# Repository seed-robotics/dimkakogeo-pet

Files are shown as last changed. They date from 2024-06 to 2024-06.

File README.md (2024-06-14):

# PetFeeder Project
## Περιγραφή 
Θέλοντας να βοηθήσουμε στο πρόβλημα ταΐσματος των κατοικίδιων ζώων η ομάδα μας κατασέυσασε μια αυτόματη ταΐστρα. Ψάχνοντας στο διαδίκτυο είδαμε ότι αν και υπάρχουν αρκετές αυτόματες ταΐστρες, οι περισσότερες δεν αφορούν παραπάνω από ένα ζώο ή δεν έχουν δυνατότητα να βγάζουν διαφορετικές τροφές. Επειδή οι σκύλοι έχουν διαφορετικές διατροφικές ανάγκες σε σχέση με τις γάτες σκεφτήκαμε να φτιάξουμε μια ταΐστρα η οποία μέσω Τεχνητής Νοημοσύνης να μπορεί να ξεχωρίσει τι είδους ζωάκι υπάρχει εκείνη τη στιγμή στο προσκήνιο και να προσφέρει το κατάλληλο είδος τροφής. 

Aποτελείται από δύο δοχεία αποθήκευσης της ξηράς τροφής, ένα το οποίο περιέχει κατάλληλη τροφή για γάτες και ένα για σκύλους. Ανάλογα με το είδος του ζώου που έχει πλησιάσει, ενεργοποιείται και διαφορετικός κινητήρας και ελευθερώνεται τροφή από διαφορετικό δοχείο ώστε να καταλήγει στο μπολ. Η ανίχνευση της κίνησης γίνεται μέσω της κάμερας και όταν περάσει κάτι μπροστά από την ταΐστρα και γίνει ανίχνευση κίνησης, η εικόνα αυτή τροφοδοτείται σε μοντέλο μηχανικής μάθησης αναγνώρισης εικόνας. Ανάλογα με το αποτέλεσμα (γάτα/σκύλος/υπόβαθρο) ενεργοποιείται και ο αντίστοιχος κινητήρας. 

<div style="display: flex; justify-content: center;">
  dimkakogeopet
</div>

Εκτός από αναγνώριση γάτας/σκύλου/υποβάθρου θα μπορεί με μικρές αλλαγές να χρησιμοποιηθεί και μόνο για ένα είδος ζώου(πχ δύο σκύλοι με διαφορετικό μέγεθος ή ένα δοχείο με τροφή ένα με λιχουδιές, αλλεργίες κλπ.) ή σε εξωτερικό χώρο προσφέροντας τροφή σε αδέσποτα ζώα. Επίσης μελλοντικά μπορούν να προστεθούν και άλλες λειτουργίες όπως λειτουργία παρακολούθησης μέσω βίντεο, εισαγωγή αισθητήρων πίεσης με σκοπό την εκπαίδευση του κατοικίδιου, απομακρυσμένη λειτουργία μέσω Wifi κ.α.

## Λίστα Υλικών
- Raspberry Pi Zero 2 W
- microSD card
- Raspberry Pi Camera Module
- Raspberry Pi Zero Camera Adapter
- 2*Servo mg996r
- mini HDMI to HDMI cable
- microUSB power Supply

## Οδηγίες κατασκευής 
Για την εκτύπωση μπορείτε να βρείτε τα αρχεία στον φάκελο STLs. 
Επιπλέον για την κατασκευή θα χρειαστείτε:
- 8x M2.5 mm x 12mm βίδες για την στήριξη της κάμερας και του Raspberry Pi
- 2x M3mm x 10-30mm βιδες για την στήριξη του κοχλία
- 4x Μ3 x 10mm βίδες βίδες

## Οδηγίες για το πρόγραμμα
Σε καινούργια εγκατάσταση του Raspberry Pi OS: 
```
sudo apt update
sudo apt upgrade
sudo apt install python3-pip
cd dimkakogeo-pet/code
pip3 install -r requirements.txt
```
Στη συνέχεια μπορείτε να τρέξετε το πρόγραμμα main.py 
```
./main.py
```

## About Us
- **Όνομα Ομάδας:** DimKakoGeo-Pet
- **Μέλη Ομάδας:**
  - Δημητρης Ματσούκας
  - Γιάννης Κακογιαννάκης
  - Δημήτρης Γεωργιάδης
  - Πέτρος Κρητικός
- **Υπέυθυνος:** Λάμπρος Νέστωρας
- **Εκπαιδευτικό Κέντρο:** Seed Robotics

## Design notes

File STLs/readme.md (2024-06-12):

## Οδηγίες 

Για τη συναρμολόγηση θα χρειαστείτε:

- 1x main_left 
- 1x main_right
- 2x feed_screw
- 4x podi
- 2x screw_support
- 1x slides (optional)

Support θα χρειαστουν κυρίως στην αρχή της εκτυπωσης των κοχλίων καθώς και στις μεγάλες τρύπες των δύο δοχείων

### Παράμετροι Εκτύπωσης
- Layer height: 0.25mm
- Infill: 30%
- Speed: 50-65 mm/s

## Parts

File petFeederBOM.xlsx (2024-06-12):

Υλικό | Link | Κόστος
Raspberry Pi Zero 2 W | https://nettop.gr/index.php/raspberry-pi/raspberry-pi-zero/raspberry-pi-zero-kits/raspberry-pi-zero-2-w.html | 20
microSD card | https://www.devobox.com/el/memory-cards/497-sandisk-ultra-microsdhc-uhs-i-a1-32gb-class-10-with-adapter.html | 10
Raspberry Pi Camera Module | https://nettop.gr/index.php/raspberry-pi/camera/raspberry-pi-camera-module-3.html | 33
Raspberry Pi Zero Camera Adapter | https://grobotronics.com/raspberry-pi-zero-v1.3-camera-cable-80mm.html?sl=en | 2
1kg PLA/PETG |  | 20
2*Servo mg996r | https://www.cableworks.gr/ilektronika/motors/servo/mg996r-servo-metal-gear-high-torque-motor-for-arduino/ | 12.64
mini HDMI to HDMI cable | HDMI male to mini HDMI Cable | 3.35
power Supply | https://www.hellasdigital.gr/go-create/raspberry-and-accessories/power-supplies/5v-3a-adapter-micro-connector-power-supply/ | 2.9
Κόστος |  | 103.89

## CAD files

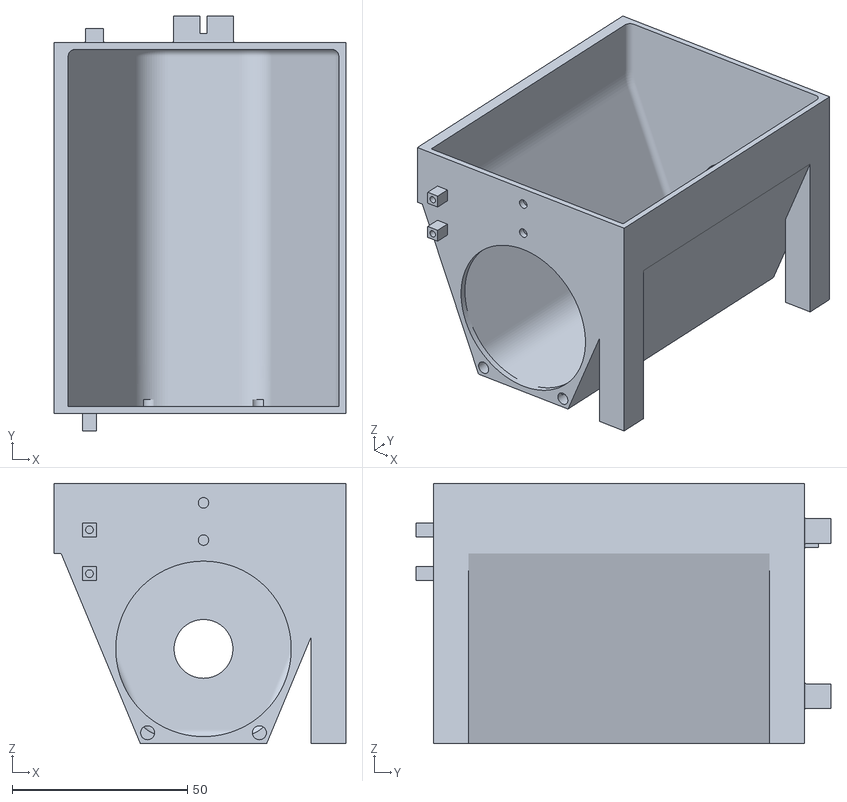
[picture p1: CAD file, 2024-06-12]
STLs/main_right.stl
83.1 x 118.3 x 74.2

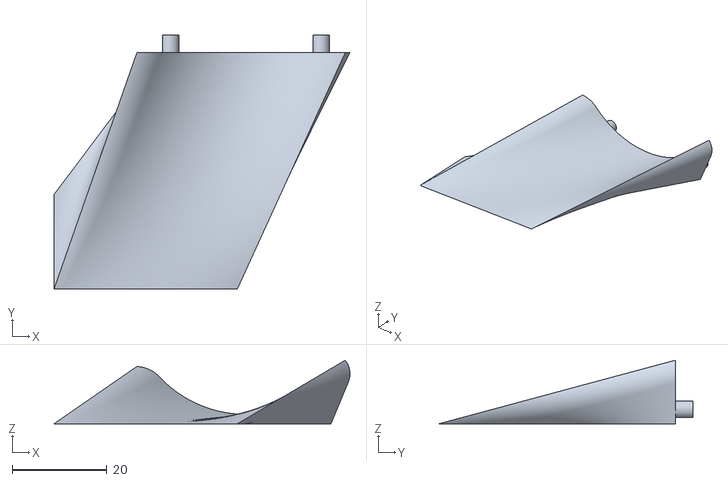
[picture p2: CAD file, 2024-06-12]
STLs/slide_left.stl
62.6 x 53.8 x 13.4

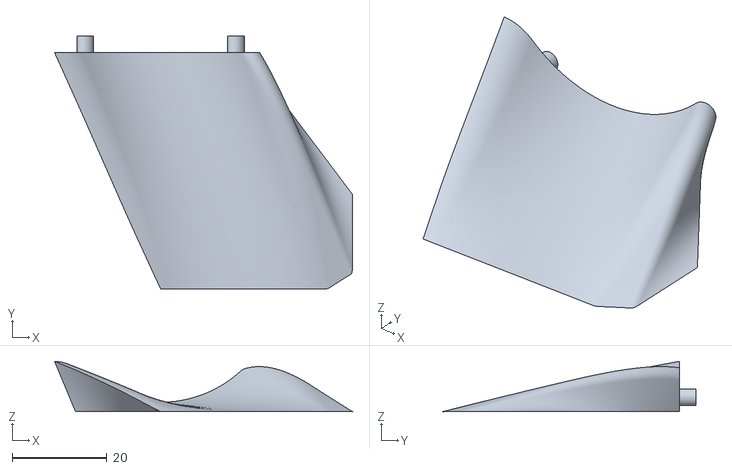
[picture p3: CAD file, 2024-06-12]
STLs/slide_right.stl
63.0 x 53.5 x 10.7

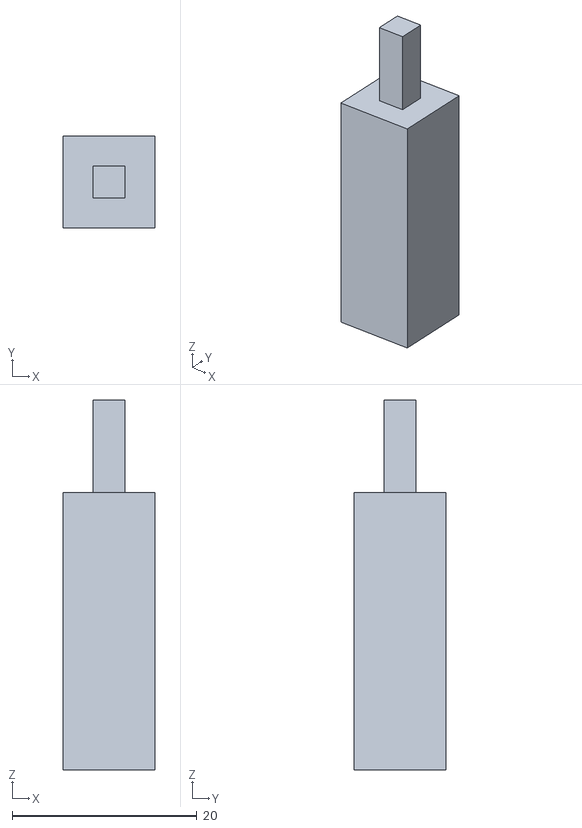
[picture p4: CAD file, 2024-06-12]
STLs/podi.stl
10.0 x 10.0 x 40.0

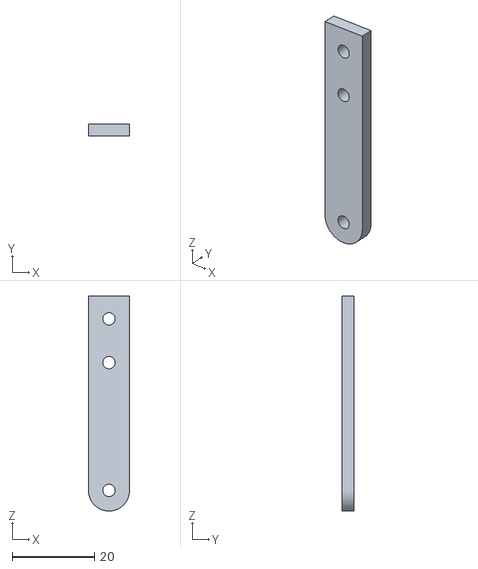
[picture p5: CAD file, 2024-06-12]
STLs/screw_support.stl
10.0 x 3.00 x 52.2

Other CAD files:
STLs/main_left.stl

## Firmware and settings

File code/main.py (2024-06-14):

#!/usr/bin/python3
import RPi.GPIO as GPIO
import time
from keras.models import load_model
import cv2
import numpy as np
from picamera2 import Picamera2
from time import sleep

# Thresholds and init for motion
pixel_threshold = 35
motion_threshold = 10000
previous_green = None

# Set the pin number where your servo is connected. One for dog(18) one for cat(17)
servo_pin1 = 18
servo_pin2 = 17

def prediction(im):
    im = cv2.resize(im, (224, 224), interpolation=cv2.INTER_AREA)
    im = np.asarray(im, dtype=np.float32)
    im = (im / 127.5) - 1
    im = im.reshape(1, 224, 224, 3) 
    # Predict using the model
    prediction = model.predict(im)
    index = np.argmax(prediction)
    class_name = class_names[index]
    confidence_score = prediction[0][index]
    # Print prediction and confidence score
    print("Class:", class_name[2:], end="")
    print("Confidence Score:", str(np.round(confidence_score * 100))[:-2], "%")
    if(index == 0):
        return("cat")
    elif(index == 1):
        return("dog")
    else:
        return("backround")

def servo(pred):
    GPIO.setmode(GPIO.BCM)
    GPIO.setup(servo_pin1, GPIO.OUT)
    GPIO.setup(servo_pin2, GPIO.OUT)
    pwm1 = GPIO.PWM(servo_pin1, 50)
    pwm2 = GPIO.PWM(servo_pin2, 50)
    def angle_to_duty_cycle(angle):
        return (0.05 * angle) + 2.5
    try:
        if(pred == "cat"):
            pwm2.start(angle_to_duty_cycle(80))
            time.sleep(3)
        if(pred == "dog"):
            pwm1.start(angle_to_duty_cycle(80))
            time.sleep(3)

    except KeyboardInterrupt:
        print("Exiting")

    finally:
        pwm1.stop()
        pwm2.stop()
        GPIO.cleanup()

# Load the model and labels
timenow=time.time()
model = load_model("./models/cats_dogs/keras_model.h5", compile=False)
class_names = open("./models/cats_dogs/labels.txt", "r").readlines()

# Initialize picamera2
picam2 = Picamera2()
picam2.start()
print("starting Motion Detection")

while True:
    im = picam2.capture_array()

    if im.shape == (480, 640, 4):

        im = im[:, :, :3]
        # store green channel for motion detection
        current_green = im[:, :, 1]

        if previous_green is not None:
            
            current_green = current_green.astype(np.int16)
            # previous_green = previous_green.astype(np.int16)
            difference = np.abs(current_green - previous_green)
            significant_changes = difference > pixel_threshold
            motion_sum = np.sum(significant_changes)

            if motion_sum > motion_threshold:
                print("Motion detected!")
                if(prediction(im)=="cat"):
                    servo("cat")
                elif(prediction(im)=="dog"):
                    servo("dog")

        previous_green = current_green.copy()

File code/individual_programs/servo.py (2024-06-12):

import RPi.GPIO as GPIO
import time

GPIO.setmode(GPIO.BCM)

servo_pin1 = 18
servo_pin2 = 17

# Set PWM parameters
GPIO.setup(servo_pin1, GPIO.OUT)
GPIO.setup(servo_pin2, GPIO.OUT)
pwm1 = GPIO.PWM(servo_pin2, 50)  # 50 Hz (20 ms PWM period)
pwm2 = GPIO.PWM(servo_pin1, 50)

def angle_to_duty_cycle(angle):
    return (0.05 * angle) + 2.5

try:
    pwm1.start(angle_to_duty_cycle(80))
    # Keep the servo at 80 degrees for 1 second
    time.sleep(1)
    pwm1.start(angle_to_duty_cycle(100))
    # Keep the servo at 110 degrees for 1 second
    time.sleep(1)

except KeyboardInterrupt:
    pass

finally:
    pwm1.stop()
    GPIO.cleanup()

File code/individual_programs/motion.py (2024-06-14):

#!/usr/bin/python3

from keras.models import load_model
import cv2
import numpy as np
from picamera2 import Picamera2
from libcamera import controls
from time import sleep


# Thresholds and init
pixel_threshold = 35
motion_threshold = 10000
previous_green = None
# Disable scientific notation for clarity
np.set_printoptions(suppress=True)

# Initialize Picamera2
picam2 = Picamera2()
picam2.start()
picam2.set_controls({"AfMode": controls.AfModeEnum.Continuous})
print("starting Motion Detection")
while True:
    im = picam2.capture_array()
    # print(im)
    # print(im.shape)
    if im.shape == (480, 640, 4):
        # Extract the RGB channels and ignore the alpha channel
        im = im[:, :, :3]
        green = im[:, :, 1]

        current_green = im[:, :, 1]
        # print(previous_green)
        if previous_green is not None:
            current_green = current_green.astype(np.int16)
            previous_green = previous_green.astype(np.int16)
            #abs = absolut 
            difference = np.abs(current_green - previous_green)
            significant_changes = difference > pixel_threshold
            motion_sum = np.sum(significant_changes)
            print("sum:", motion_sum)

            if motion_sum > motion_threshold:
                print(significant_changes)
                print("Motion detected!")

        previous_green = current_green.copy()

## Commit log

2024-01-30 Added Bill Of Materials
    [petFeederBOM.xlsx]
2024-06-12 STLs, BOM and some code
    [main_left.stl, main_right.stl, petFeederBOM.xlsx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]
